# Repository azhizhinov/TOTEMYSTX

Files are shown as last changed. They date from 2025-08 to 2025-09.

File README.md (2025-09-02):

# TOTEMYSTX
TOTEMYSTX is a 38-40 keys column-staggered split keyboard. It meant to be used with a Seed Studio XIAO RP2040 or nRF52840.
TOTEMYSTX is a replica of the famous TOTEM by GEIGEIGEIST for MX spacing (19.05x19.05mm) switches like Cherry MX.

**Warning. I don't have printed PCBs on hands, so can't check or debug. It should work in theory. Use this files on youre own risk.**

https://github.com/GEIGEIGEIST/TOTEM

TOTEMYSTX with 38 keys shares the same firmware as of the original TOTEM.
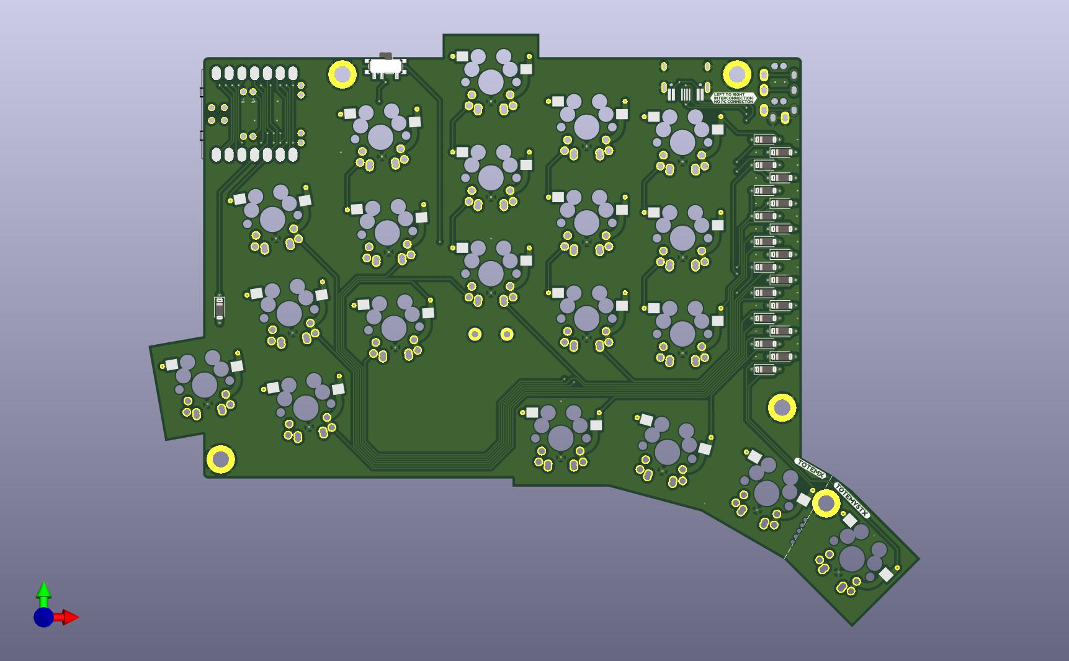
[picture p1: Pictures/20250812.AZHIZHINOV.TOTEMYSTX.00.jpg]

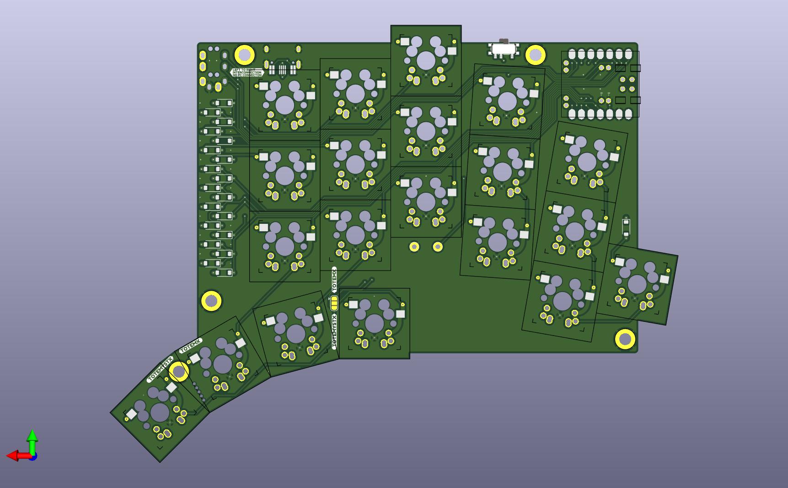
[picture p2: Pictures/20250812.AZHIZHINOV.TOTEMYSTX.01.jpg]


There are 3 mods for the TOTEMYSTX use cases.

The jumper is open. 38 keys as usual, but the right thumb key not in use, has no connection to the MCU.

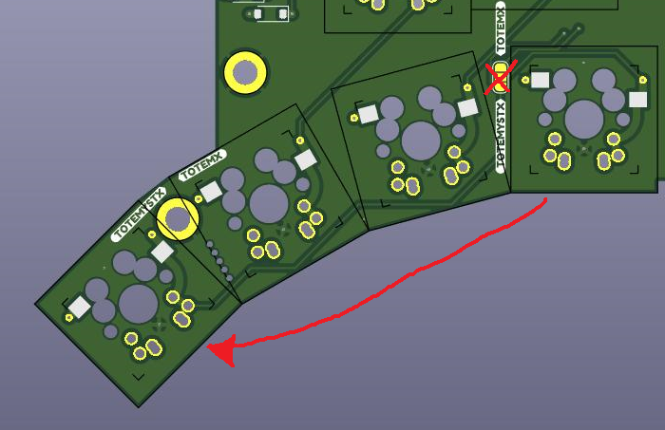
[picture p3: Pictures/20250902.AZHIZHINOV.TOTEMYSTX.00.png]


If you'll cut out the outer thumb key, you have to solder the jumper in "TOTEMX" mode. It's will be classical TOTEM/TOTEMX.

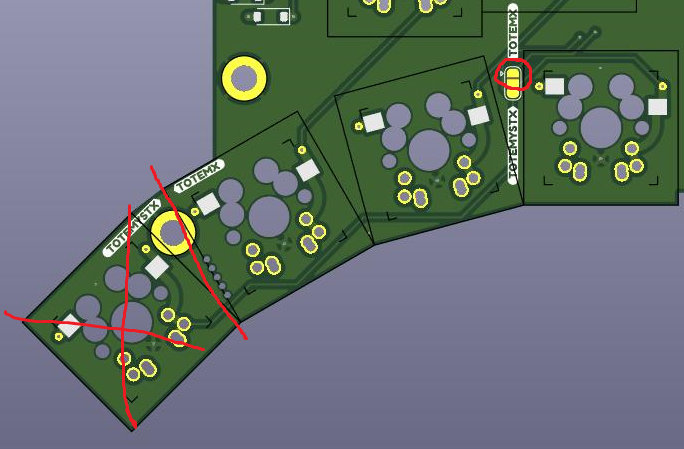
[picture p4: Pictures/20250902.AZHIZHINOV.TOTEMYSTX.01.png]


To use all 40 keys, you have to solder the jumper in "TOTEMYSTX" mode and change a keymap and recompile then.

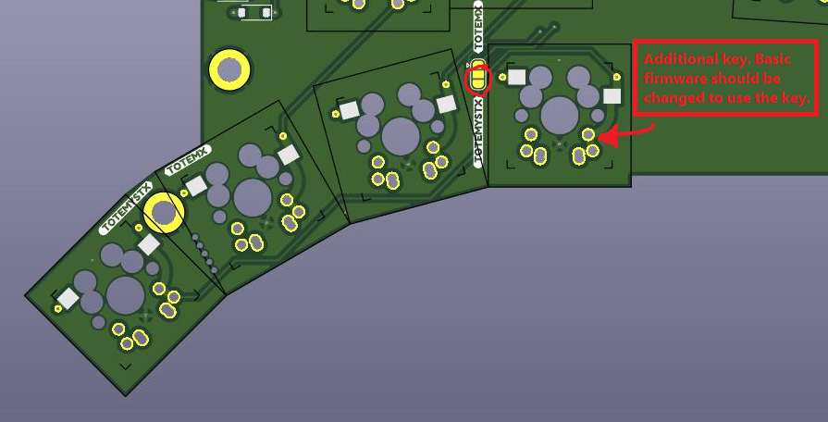
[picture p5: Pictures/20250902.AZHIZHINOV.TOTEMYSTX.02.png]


TOTEMX with 38 keys shares the same firmware as of the original TOTEM.
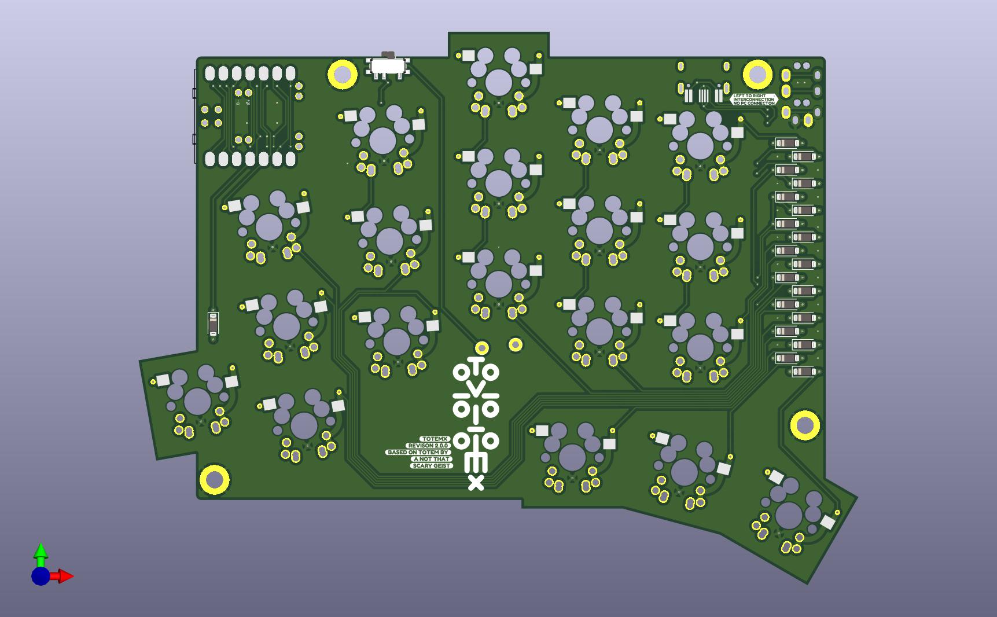
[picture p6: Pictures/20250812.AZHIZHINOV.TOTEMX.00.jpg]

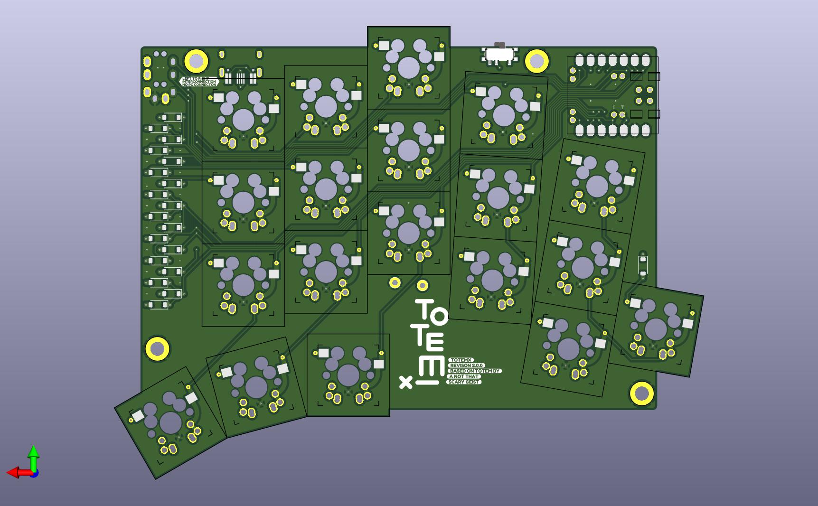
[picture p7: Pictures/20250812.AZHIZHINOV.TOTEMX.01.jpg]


Cases's models are designed to use M2 screws. For the TOTEMYSTX case use M2\*10mm -8pcs and M2\*8mm -2pcs and M2\*10mm -8pcs for the TOTEMX case.

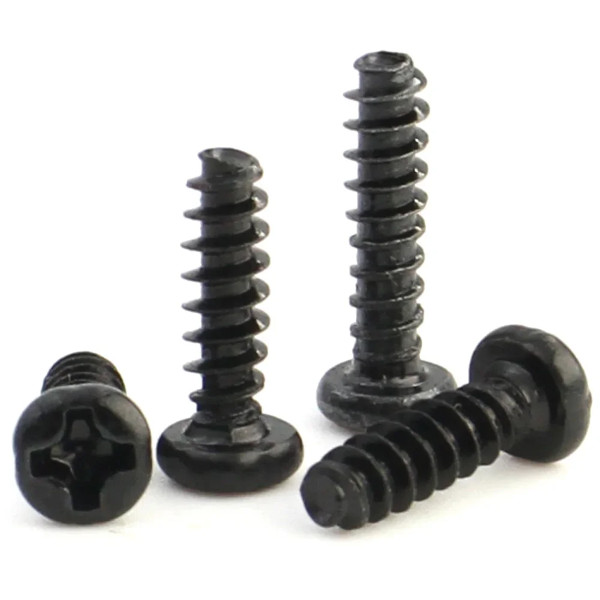
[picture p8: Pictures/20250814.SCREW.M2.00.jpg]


The cases and PCBs are not compatible with the previous version. https://github.com/azhizhinov/TOTEMX

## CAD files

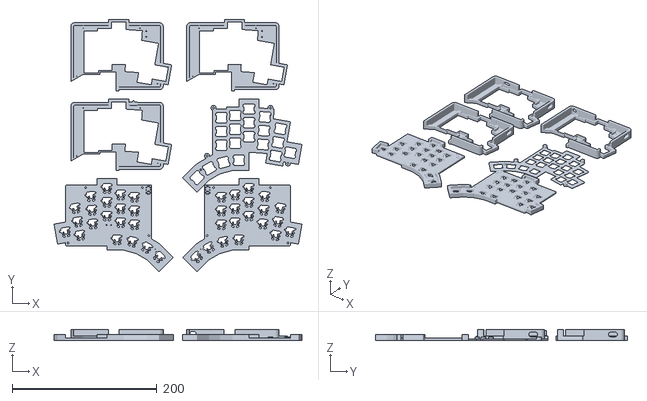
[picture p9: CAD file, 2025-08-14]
Case/20250814.AZHIZHINOV.TOTEMYSTX.00.stl
342.6 x 348.7 x 14.8

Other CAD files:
Case/20250814.AZHIZHINOV.TOTEMX.00.stl

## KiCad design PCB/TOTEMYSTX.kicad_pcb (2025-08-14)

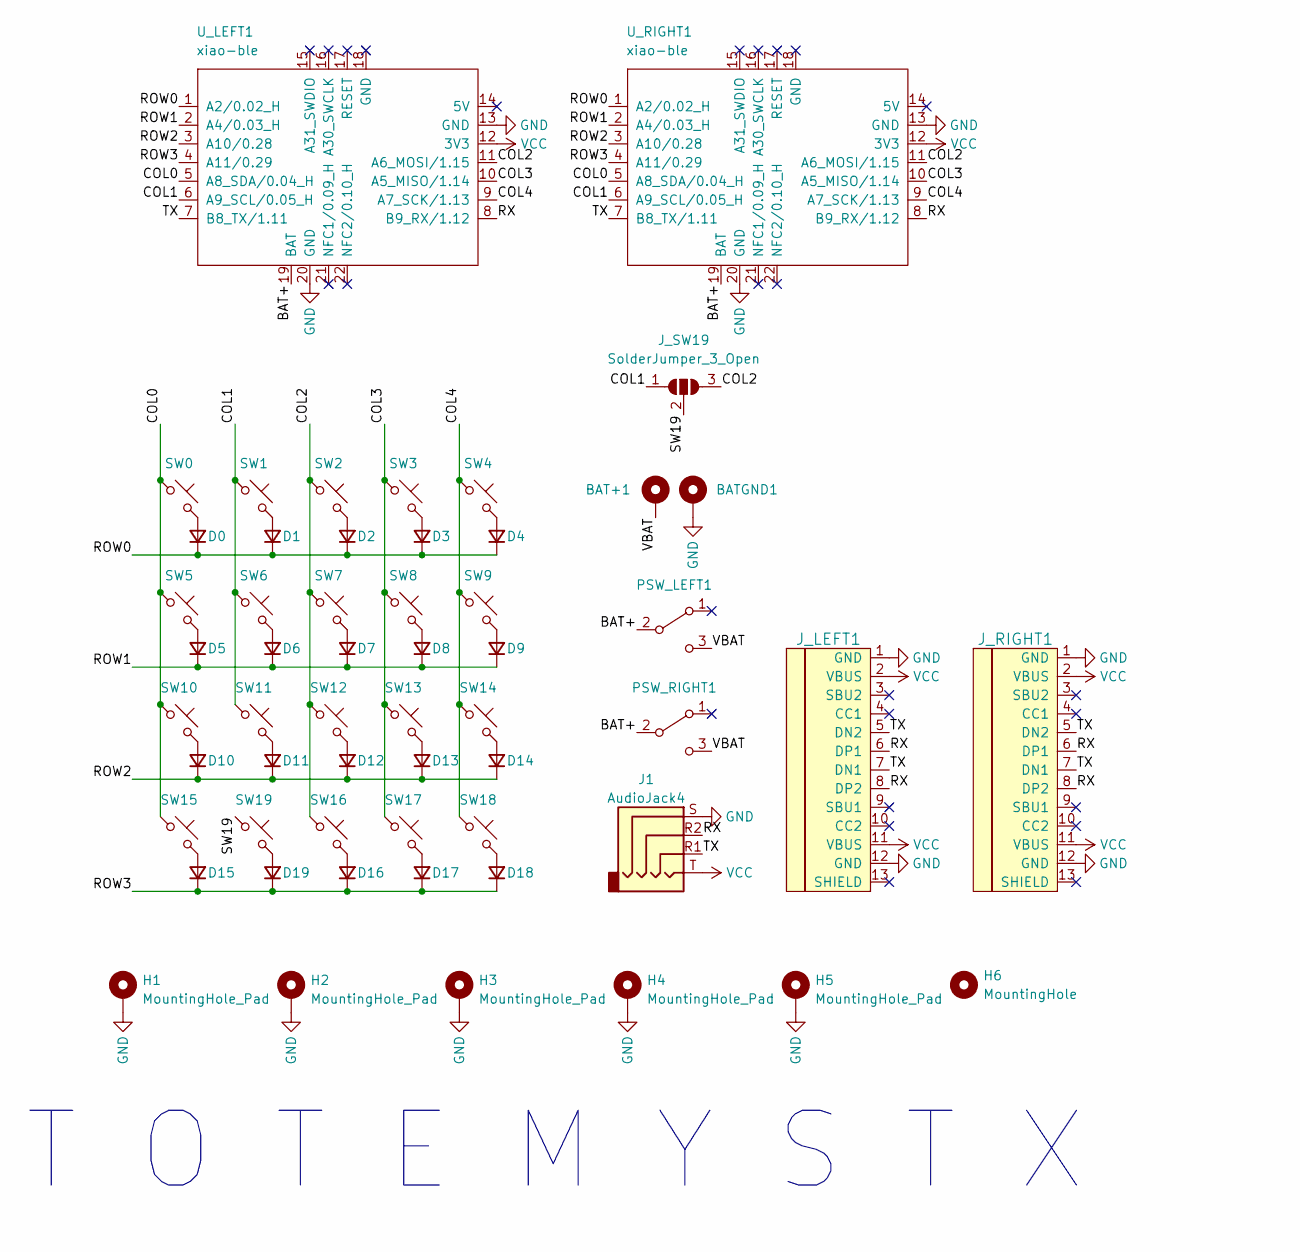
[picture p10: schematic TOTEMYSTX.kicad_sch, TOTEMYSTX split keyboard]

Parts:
BAT+1: +; BatteryPad
BATGND1: -; BatteryPad
D0, D1, D2, D3, D4, D5, D6, D7, D8, D9, D10, D11, D12, D13, D14, D15, D16, D17, D18, D19: D_Small; TOTEMYSTX-D
H1, H2, H3, H4, H5: MountingHole_Pad; TOTEMYSTX-MountingHole_3.2mm_M3_DIN965_Pad
H6: MountingHole; TOTEMYSTX-BREAKWAY
J1: AudioJack4; TOTEMYSTX-TRRS-THT
J_LEFT1: HRO-TYPE-C-31-M-12; TOTEMYSTX-TYPE-C
J_RIGHT1: HRO-TYPE-C-31-M-12; TOTEMYSTX-TYPE-C
J_SW19: SolderJumper_3_Open; TOTEMYSTX-SolderJumper-3_P1.3mm_Open_RoundedPad1.0x1.5mm
PSW_LEFT1: SW_SPDT; TOTEMYSTX-SW_SPDT_PCM12
PSW_RIGHT1: SW_SPDT; TOTEMYSTX-SW_SPDT_PCM12
SW0, SW1, SW2, SW3, SW4, SW5, SW6, SW7, SW8, SW9, SW10, SW11, SW12, SW13, SW14, SW15, SW16, SW17, SW18, SW19: SW_Push_45deg; TOTEMYSTX-KEY
U_LEFT1: xiao-ble; TOTEMYSTX-XIAO-BLE-SMD
U_RIGHT1: xiao-ble; TOTEMYSTX-XIAO-BLE-SMD

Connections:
/BAT+: PSW_LEFT1.2 (B), PSW_RIGHT1.2 (B), U_LEFT1.19 (BAT), U_RIGHT1.19 (BAT)
/COL0: SW0.1, SW5.1, SW10.1, SW15.1, U_LEFT1.5 (A8_SDA/0.04_H), U_RIGHT1.5 (A8_SDA/0.04_H)
/COL1: J_SW19.1 (A), SW1.1, SW6.1, SW11.1, U_LEFT1.6 (A9_SCL/0.05_H), U_RIGHT1.6 (A9_SCL/0.05_H)
/COL2: J_SW19.3 (B), SW2.1, SW7.1, SW12.1, SW16.1, U_LEFT1.11 (A6_MOSI/1.15), U_RIGHT1.11 (A6_MOSI/1.15)
/COL3: SW3.1, SW8.1, SW13.1, SW17.1, U_LEFT1.10 (A5_MISO/1.14), U_RIGHT1.10 (A5_MISO/1.14)
/COL4: SW4.1, SW9.1, SW14.1, SW18.1, U_LEFT1.9 (A7_SCK/1.13), U_RIGHT1.9 (A7_SCK/1.13)
/ROW0: D0.1 (K), D1.1 (K), D2.1 (K), D3.1 (K), D4.1 (K), U_LEFT1.1 (A2/0.02_H), U_RIGHT1.1 (A2/0.02_H)
/ROW1: D5.1 (K), D6.1 (K), D7.1 (K), D8.1 (K), D9.1 (K), U_LEFT1.2 (A4/0.03_H), U_RIGHT1.2 (A4/0.03_H)
/ROW2: D10.1 (K), D11.1 (K), D12.1 (K), D13.1 (K), D14.1 (K), U_LEFT1.3 (A10/0.28), U_RIGHT1.3 (A10/0.28)
/ROW3: D15.1 (K), D16.1 (K), D17.1 (K), D18.1 (K), D19.1 (K), U_LEFT1.4 (A11/0.29), U_RIGHT1.4 (A11/0.29)
/RX: J1.R2, J_LEFT1.6 (DP1), J_LEFT1.8 (DP2), J_RIGHT1.6 (DP1), J_RIGHT1.8 (DP2), U_LEFT1.8 (B9_RX/1.12), U_RIGHT1.8 (B9_RX/1.12)
/SW19: J_SW19.2 (C), SW19.1
/TX: J1.R1, J_LEFT1.5 (DN2), J_LEFT1.7 (DN1), J_RIGHT1.5 (DN2), J_RIGHT1.7 (DN1), U_LEFT1.7 (B8_TX/1.11), U_RIGHT1.7 (B8_TX/1.11)
/VBAT: BAT+1.1, PSW_LEFT1.3 (C), PSW_RIGHT1.3 (C)
GND: BATGND1.1, H1.1, H2.1, H3.1, H4.1, H5.1, J1.S, J_LEFT1.1 (GND), J_LEFT1.12 (GND), J_LEFT1.13 (SHIELD), J_RIGHT1.1 (GND), J_RIGHT1.12 (GND), J_RIGHT1.13 (SHIELD), SW0.GND, SW1.GND, SW2.GND, SW3.GND, SW4.GND, SW5.GND, SW6.GND, SW7.GND, SW8.GND, SW9.GND, SW10.GND, SW11.GND, SW12.GND, SW13.GND, SW14.GND, SW15.GND, SW16.GND, SW17.GND, SW18.GND, SW19.GND, U_LEFT1.13 (GND), U_LEFT1.20 (GND), U_RIGHT1.13 (GND), U_RIGHT1.20 (GND)
unnamed: D0.2 (A), SW0.2
unnamed: D1.2 (A), SW1.2
unnamed: D2.2 (A), SW2.2
unnamed: D3.2 (A), SW3.2
unnamed: D4.2 (A), SW4.2
unnamed: D5.2 (A), SW5.2
unnamed: D6.2 (A), SW6.2
unnamed: D7.2 (A), SW7.2
unnamed: D8.2 (A), SW8.2
unnamed: D9.2 (A), SW9.2
unnamed: D10.2 (A), SW10.2
unnamed: D11.2 (A), SW11.2
unnamed: D12.2 (A), SW12.2
unnamed: D13.2 (A), SW13.2
unnamed: D14.2 (A), SW14.2
unnamed: D15.2 (A), SW15.2
unnamed: D16.2 (A), SW16.2
unnamed: D17.2 (A), SW17.2
unnamed: D18.2 (A), SW18.2
unnamed: D19.2 (A), SW19.2
VCC: J1.T, J_LEFT1.2 (VBUS), J_LEFT1.11 (VBUS), J_RIGHT1.2 (VBUS), J_RIGHT1.11 (VBUS), U_LEFT1.12 (3V3), U_RIGHT1.12 (3V3)

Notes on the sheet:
T O T E M Y S T X

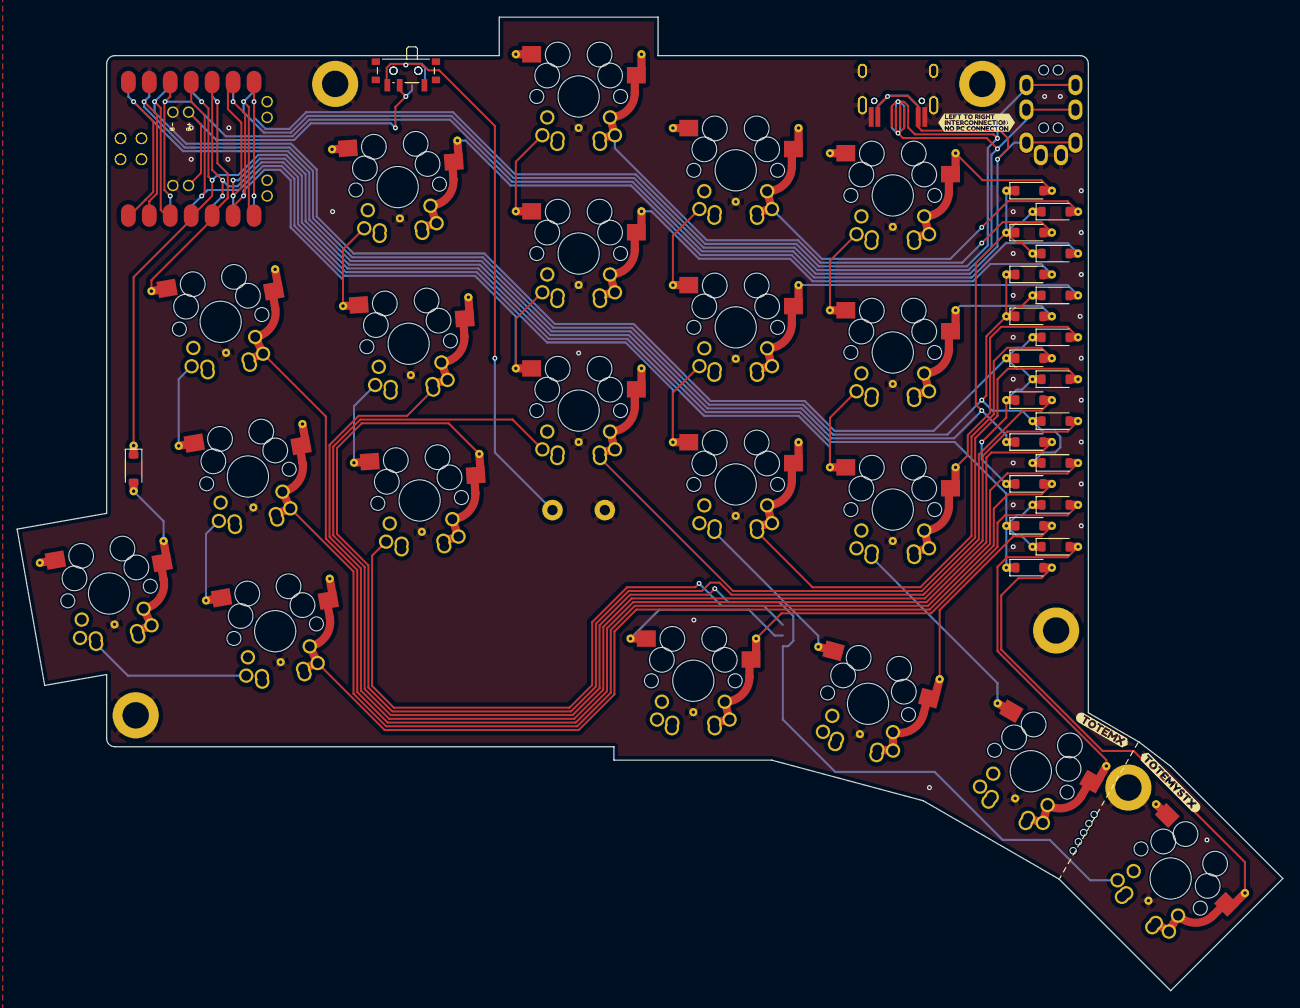
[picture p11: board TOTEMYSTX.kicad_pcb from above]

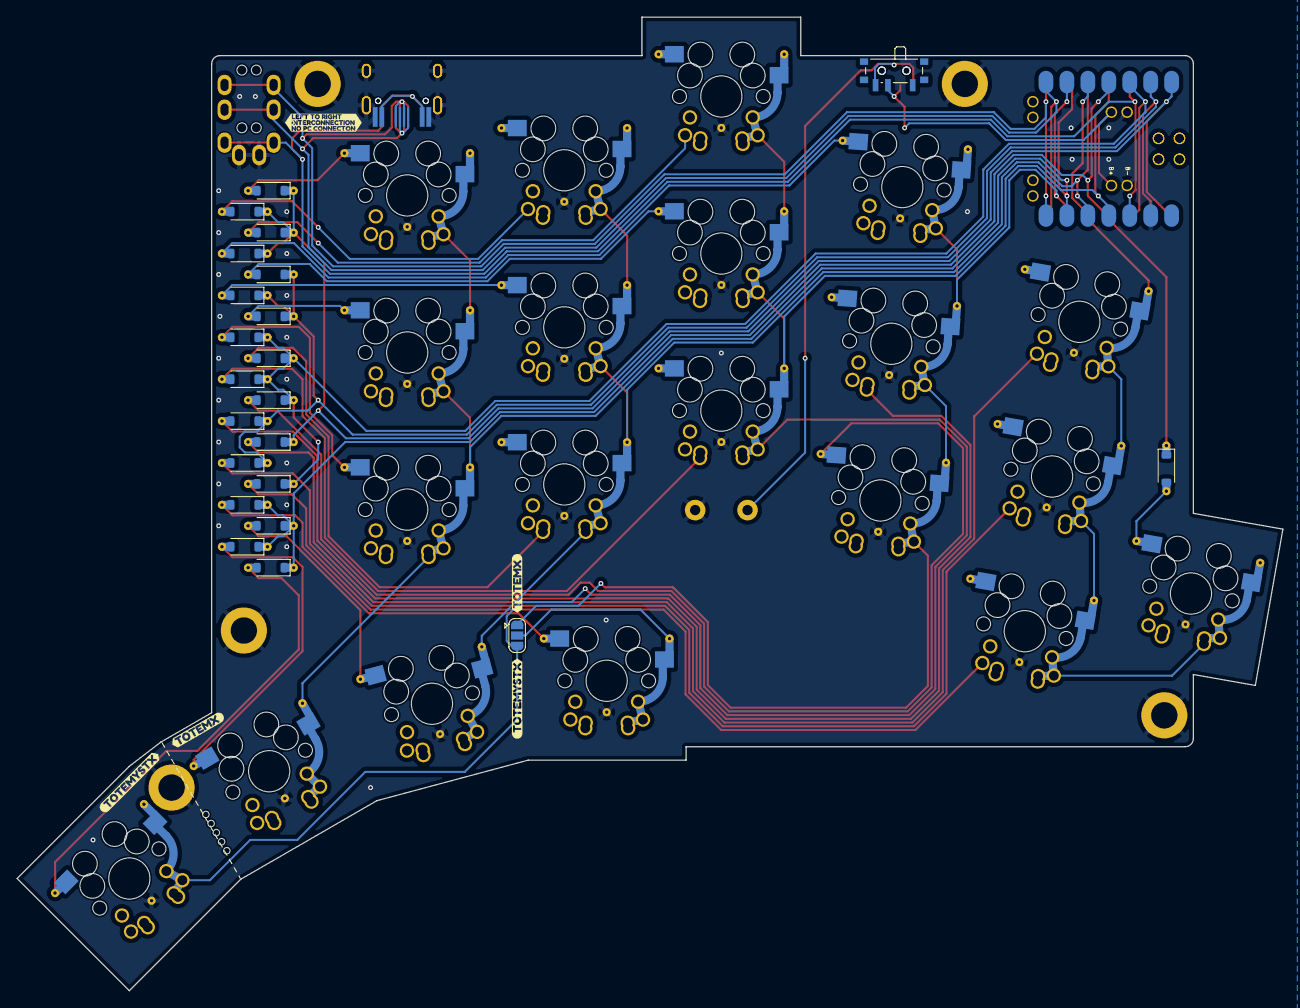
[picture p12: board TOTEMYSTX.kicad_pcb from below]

Board: 2 copper layers, 153.5 x 118.1 mm, 64 parts (9 on the bottom side), 36 nets.

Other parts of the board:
kibuzzard-688F7691, kibuzzard-688F7691#2: G***; kibuzzard-688F7691
kibuzzard-68974A0B: G***; kibuzzard-68974A0B
kibuzzard-68974A8D: G***; kibuzzard-68974A8D
kibuzzard-68974A33: G***; kibuzzard-68974A33
kibuzzard-68974A68: G***; kibuzzard-68974A68
kibuzzard-68974C18, kibuzzard-68974C18#2: G***; kibuzzard-68974C18

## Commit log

2025-08-14 Initial upload
    [20250814.AZHIZHINOV.TOTEMX.00.stl, 20250814.AZHIZHINOV.TOTEMYSTX.00.stl, TOTEMX.kicad_pcb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]
2025-08-15 Add gerbers
